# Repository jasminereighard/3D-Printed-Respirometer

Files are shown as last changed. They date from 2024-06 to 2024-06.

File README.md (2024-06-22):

3D-Printed-Respirometer
STL files for 3D printed respirometer chamber

Attached are the STL files for the 3D respirometer, along with printing instructions below.

This respirometer design is intended for intermittent-flow respirometry. The cone-bottom design helps keep sediments suspended during measurement cycles.

When you click on the files in the mainbranch, github shows a preview of the stl that looks crazy but the files work just fine. 
Here is a link to the filament we used.
https://www.prusa3d.com/product/prusament-petg-chalky-blue-1kg/

To make the respirometers watertight, we used the print settings described below. 
Additionally, we coated the respirometers with this epoxy, thinned out with 90% rubbing alcohol.
https://a.co/d/fZJ7Reo

Printing Instructions
Print the chamber, lid, and filter separately.
Print the chamber and lid face down.
Watertight Print Settings (PrusaSlicer)
Layer Height: 0.10mm (DETAIL)
Filament: Prusament PETG
Infill: 60%
Supports: On build plate only
Support Blockers: Add on all areas with threads
Print Settings Tab
Vertical Shells: 8 perimeters
Seam Position: Random
Horizontal Shells: Top and bottom layers: 6 each (lid only)
Filament Settings Tab
Extrusion Multiplier: Increase by 10% from the default value
Nozzle Temperature: Increase by 10°C for both the first and other layers

Please feel free to email me if any of the information I have provided is unclear!

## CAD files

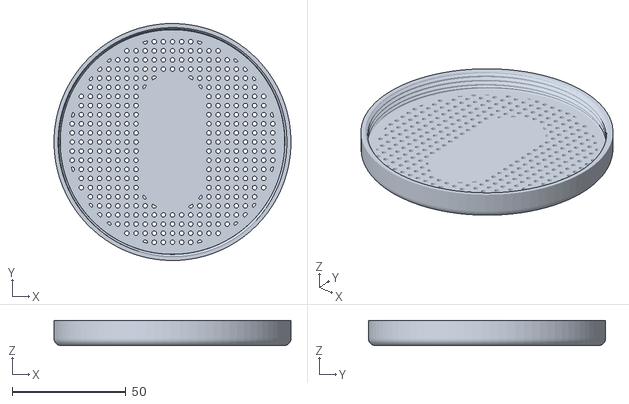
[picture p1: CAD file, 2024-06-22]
PressureReliefGrid_15cm.stl
104.0 x 104.0 x 11.0

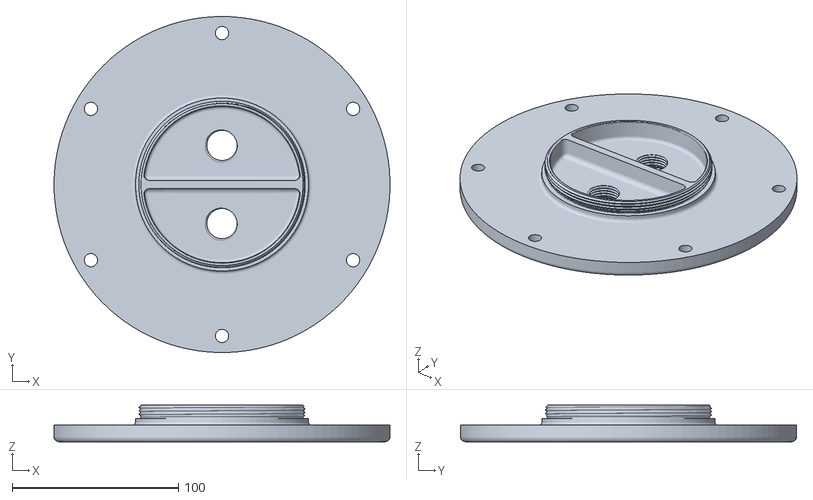
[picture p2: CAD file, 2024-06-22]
RespirometerLid_15cm.stl
202.0 x 202.0 x 22.0

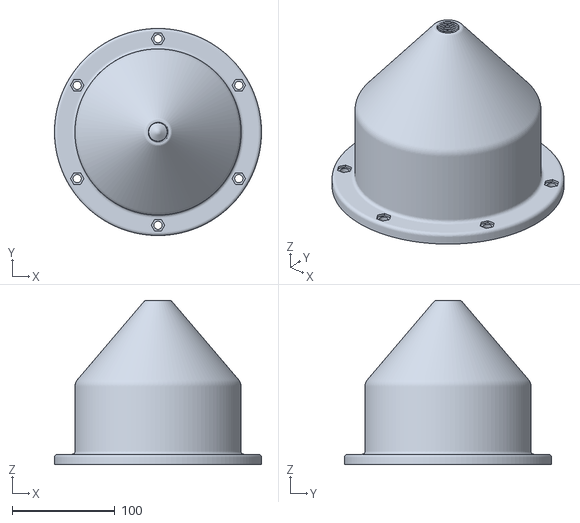
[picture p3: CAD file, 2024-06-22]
RespirometerChamber_15cm.stl
201.9 x 201.9 x 160.0

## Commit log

2024-06-22 Update README.md
    Instructions for 3d printing
2024-06-22 Respirometer chamber file
    This file prints the respirometerʻs main chamber. The diameter of the chamber is 15 cm.
    [RespirometerChamber_15cm.stl]
2024-06-22 Respirometer lid file
    This file prints the lid to the respirometer chamber
    [RespirometerLid_15cm.stl]
2024-06-22 Pressure Relief Grid File
    This file prints the pressure relief grid. This part screws onto the threads printed on the lid!
    [PressureReliefGrid_15cm.stl]
2024-06-22 trying to upload lid and not look crazy
    [LidFlow_Fix_Respirometer_Sep12_2023.stl]
